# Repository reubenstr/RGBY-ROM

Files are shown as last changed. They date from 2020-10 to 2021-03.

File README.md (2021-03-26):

# RGBY-ROM

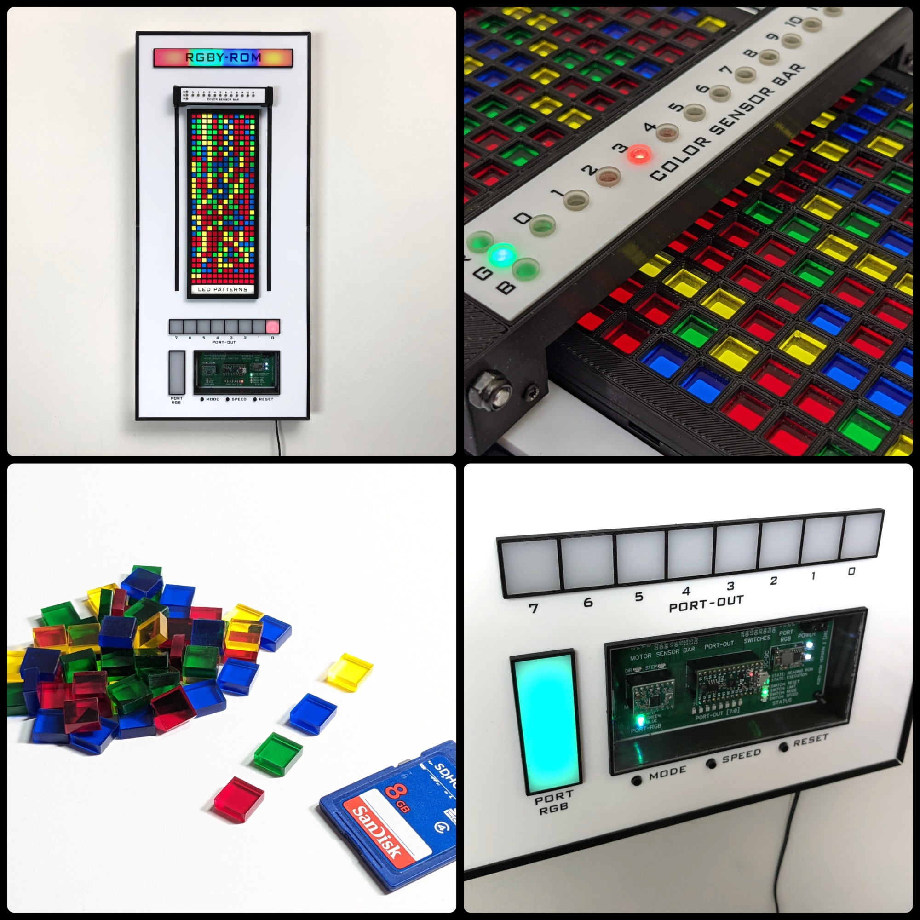
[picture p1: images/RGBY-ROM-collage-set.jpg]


RGBY-ROM reads data cartridges comprised of red, green, blue, and yellow acrylic squares where each square acts as 2 bits of program data. 

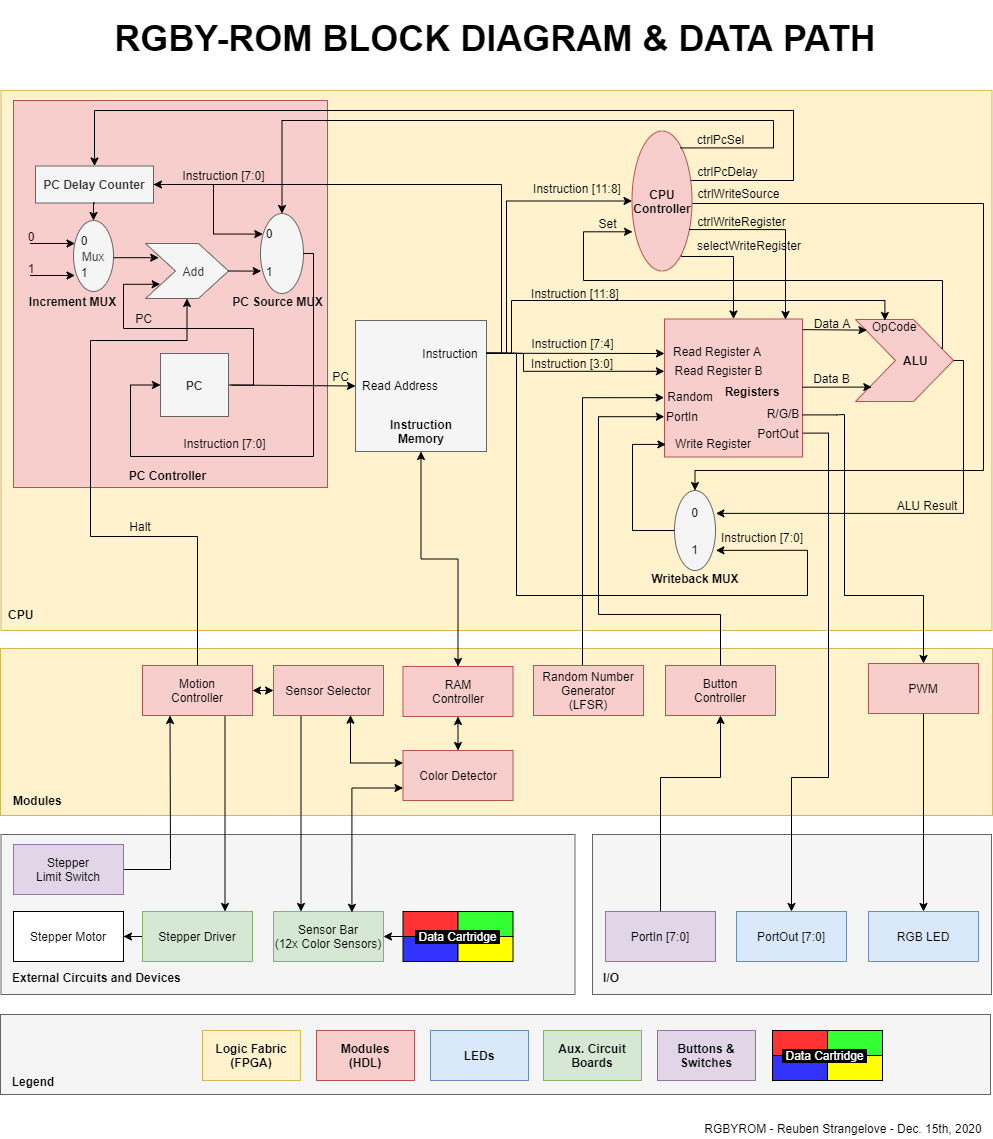
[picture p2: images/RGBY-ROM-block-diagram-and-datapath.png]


The the program is then excuted on a custom simple CPU architecture instantiated on a FPGA to control a RGB LED and 8 LED indicators.

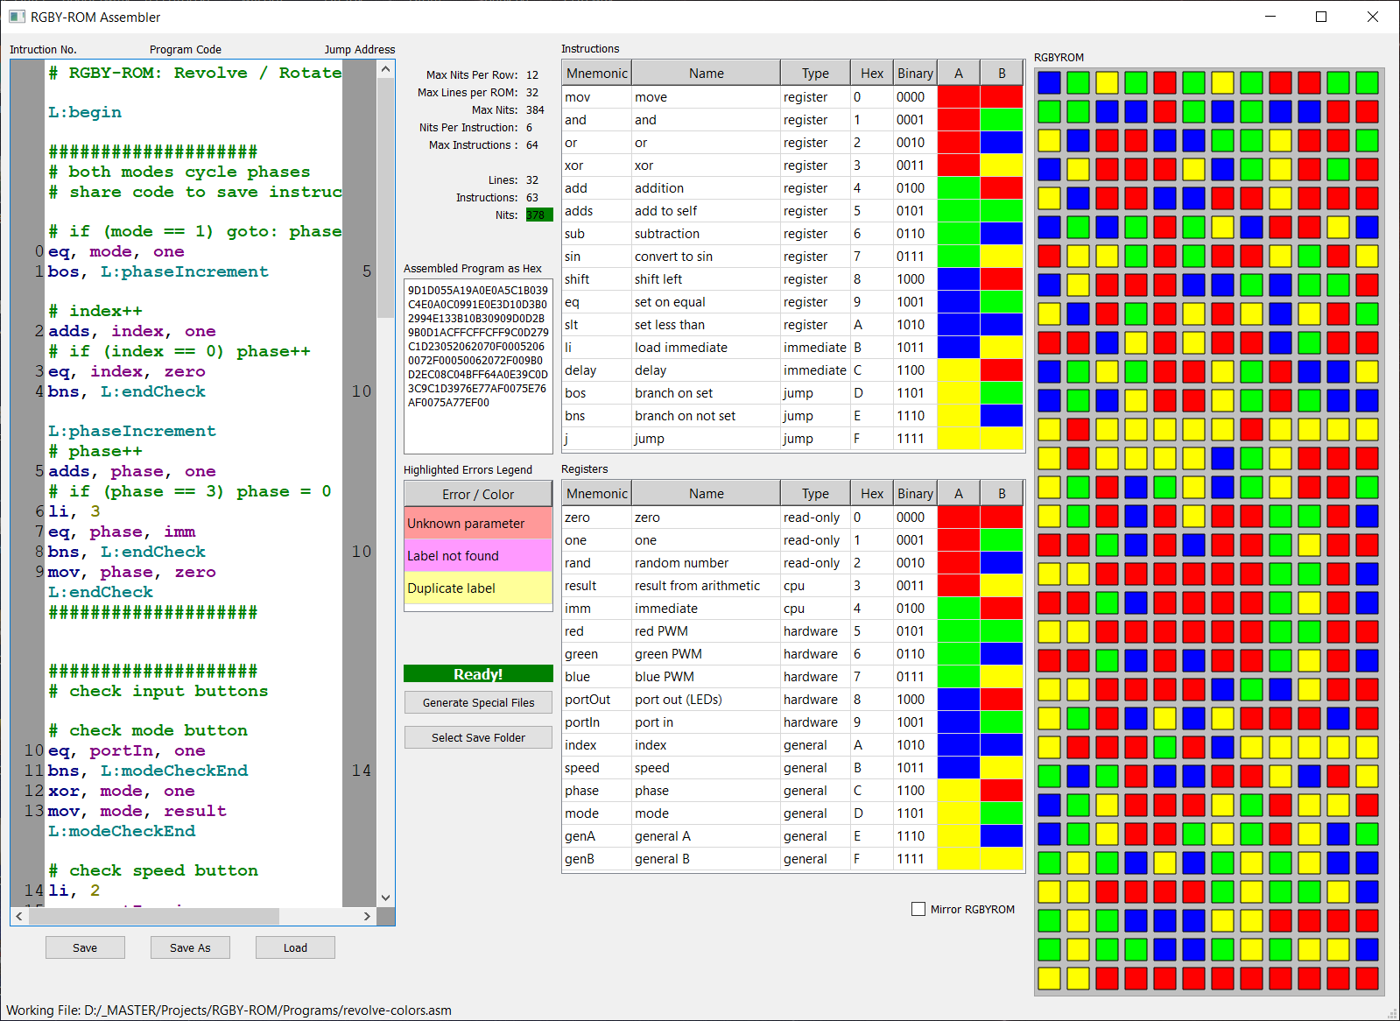
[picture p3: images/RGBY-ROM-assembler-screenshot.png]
 

The executed program is assembled using a custom assembler to create the data cartridge's color pattern.

RGBY-ROM uses the TinyFPGA Bx as the FPGA board the Verilog is developed useing the ATOM IDE with the APIO extension.

<br>

Blog post: https://metaphasiclabs.com/rgby-rom-custom-fpga-retro-cpu/

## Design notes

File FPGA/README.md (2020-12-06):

# RGBY-ROM

RGBY-ROM reads data cartridges using red, green, blue, and yellow acrylic squares as bit encoding.

***

RGBY-ROM uses the TinyFPGA Bx as the FPGA board.

The TinyFPGA uses the ATOM IDE with the APIO extension.

The HDL is Verilog.

The creator of TinyFPGA provide the following get started user guild: https://tinyfpga.com/bx/guide.html

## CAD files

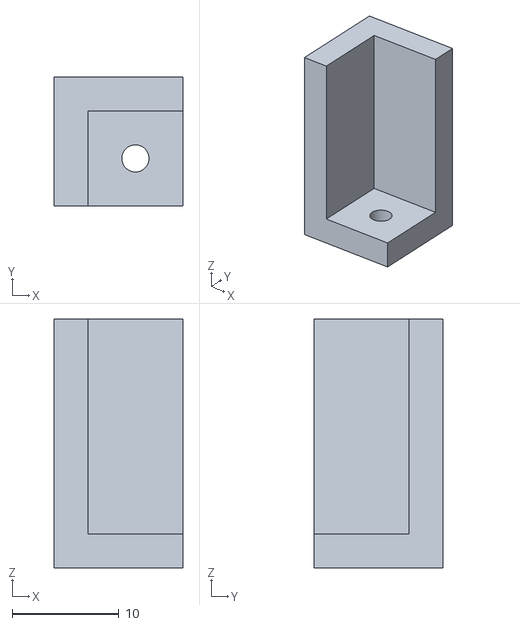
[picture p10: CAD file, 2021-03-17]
stl/RGBY-ROM-mainboard-backplate-corner-mount.stl
12.1 x 12.1 x 23.4

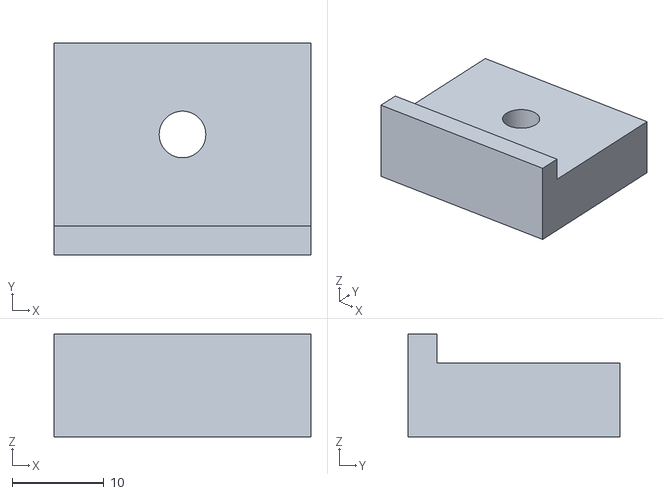
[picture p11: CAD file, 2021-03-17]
stl/RGBY-ROM-riser-a.stl
28.0 x 23.2 x 11.2

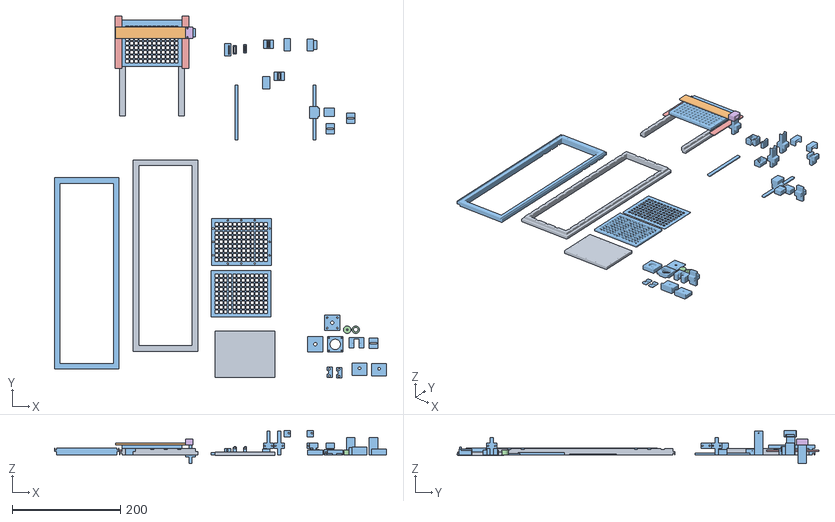
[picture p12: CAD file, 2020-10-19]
CAD/tinker.obj
613.5 x 667.9 x 61.1

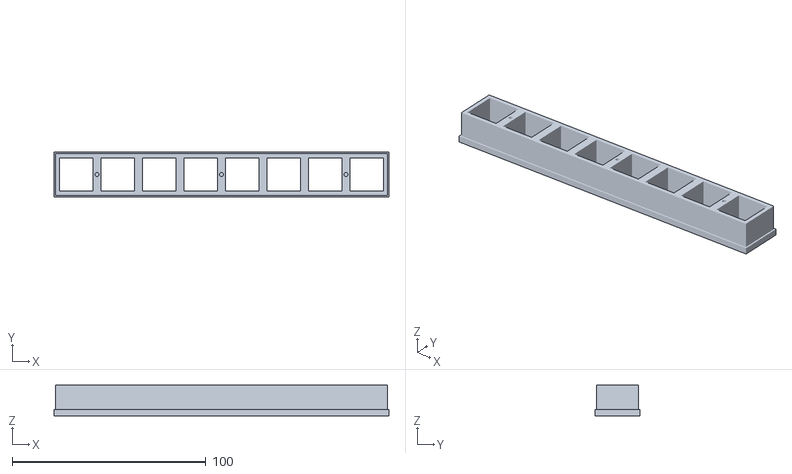
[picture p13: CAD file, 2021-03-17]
stl/RGBY-ROM-led-array-bezel.stl
172.7 x 23.0 x 15.9

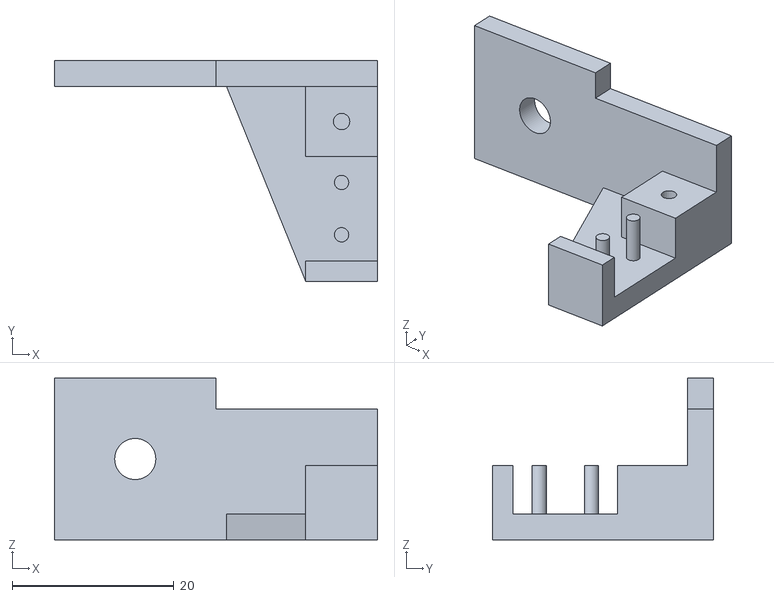
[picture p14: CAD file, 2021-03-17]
stl/RGBY-ROM-limit-switch-mounting-bracket.stl
40.0 x 27.3 x 20.0

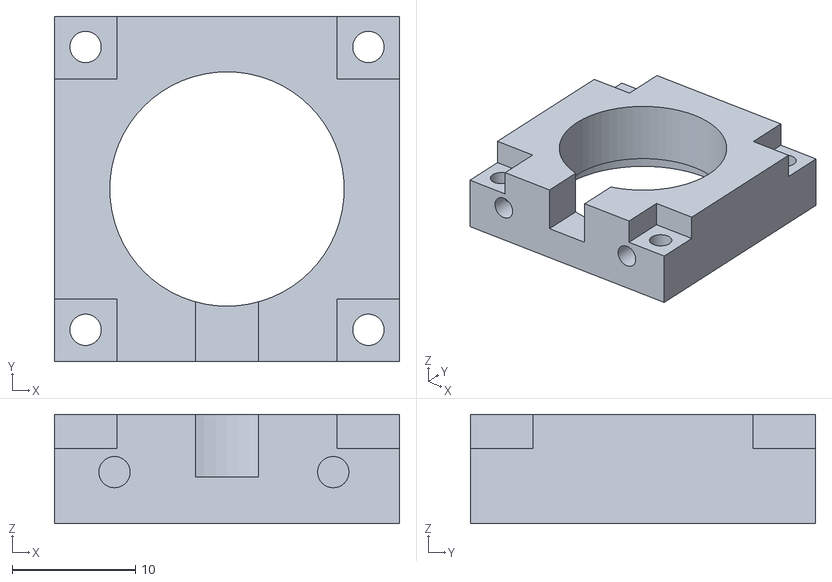
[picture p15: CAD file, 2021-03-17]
stl/RGBY-ROM-stepper-motor-mounting-bracket.stl
28.0 x 28.0 x 8.89

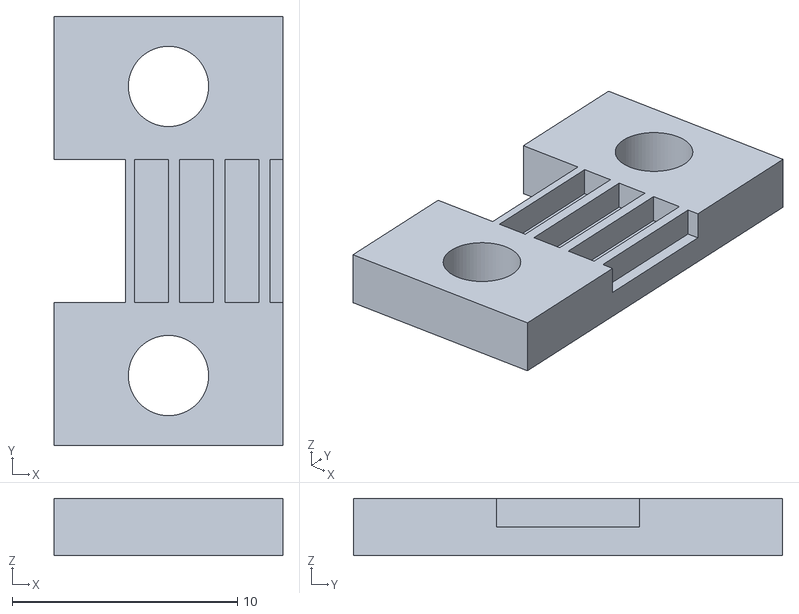
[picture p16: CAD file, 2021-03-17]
stl/RGBY-ROM-belt-hold-down.stl
10.2 x 19.1 x 2.54

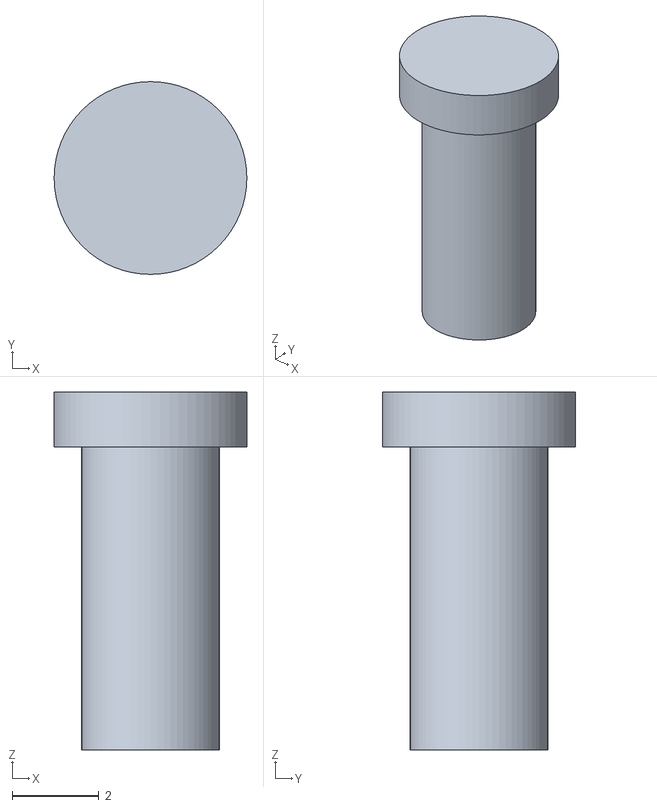
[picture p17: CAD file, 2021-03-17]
stl/RGBY-ROM-light-pipe-for-resin-printer.stl
4.44 x 4.44 x 8.26

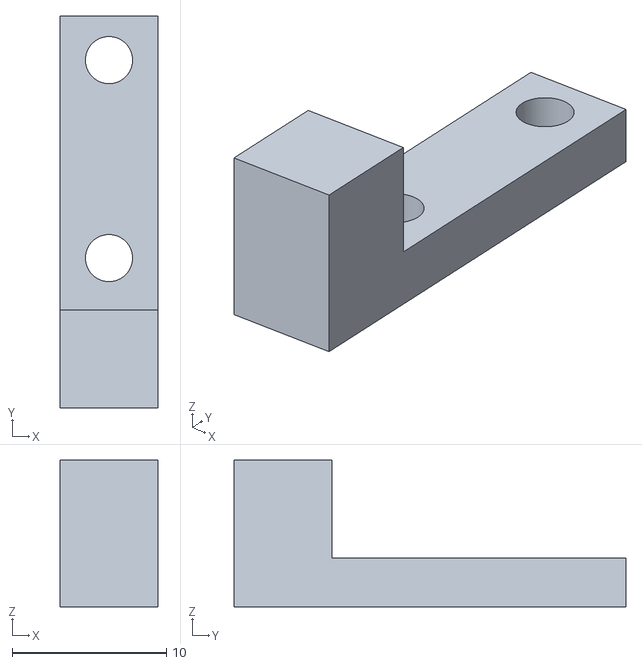
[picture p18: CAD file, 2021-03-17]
stl/RGBY-ROM-sensor-truck-limit-arm.stl
6.35 x 25.4 x 9.53

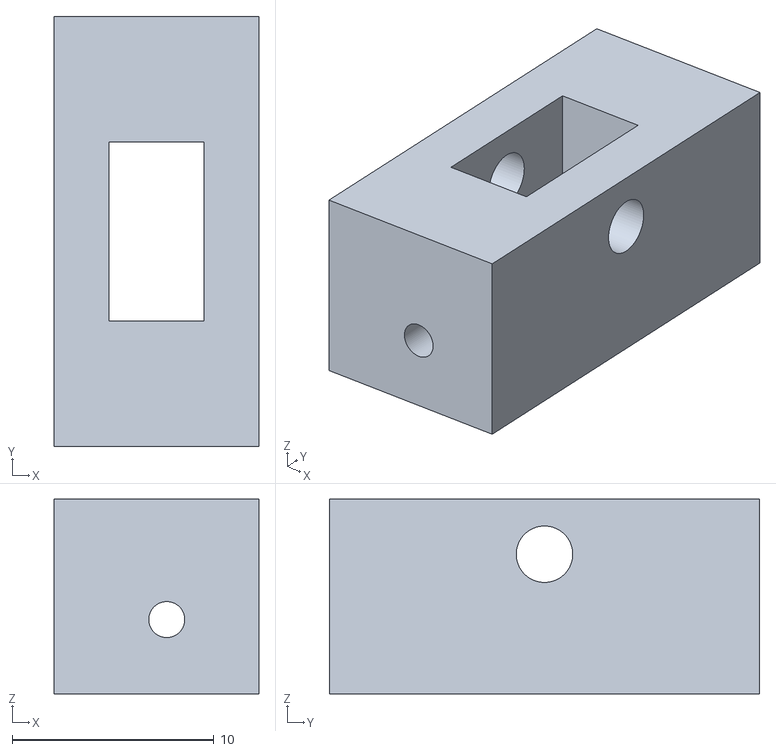
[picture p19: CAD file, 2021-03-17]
stl/RGBY-ROM-sensor-bar-bearing-block.stl
10.2 x 21.3 x 9.65

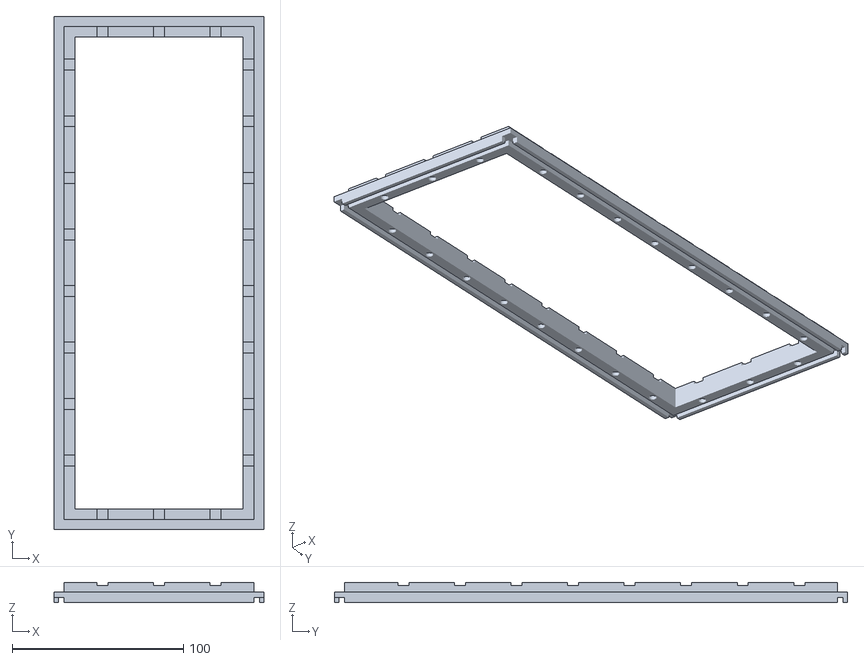
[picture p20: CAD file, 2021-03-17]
stl/RGBY-ROM-data-cartridge-magentic-mounting-bracket.stl
122.3 x 299.5 x 11.9

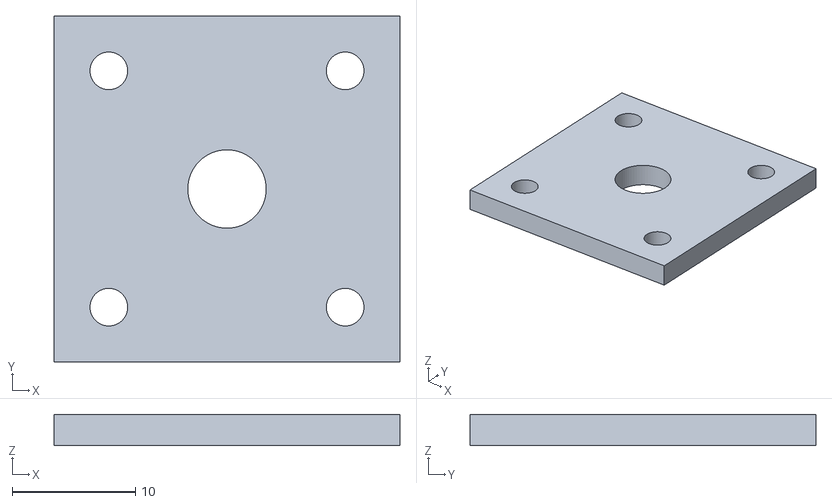
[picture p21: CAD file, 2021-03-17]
stl/RGBY-ROM-bearing-block-cover-plate.stl
28.0 x 28.0 x 2.54

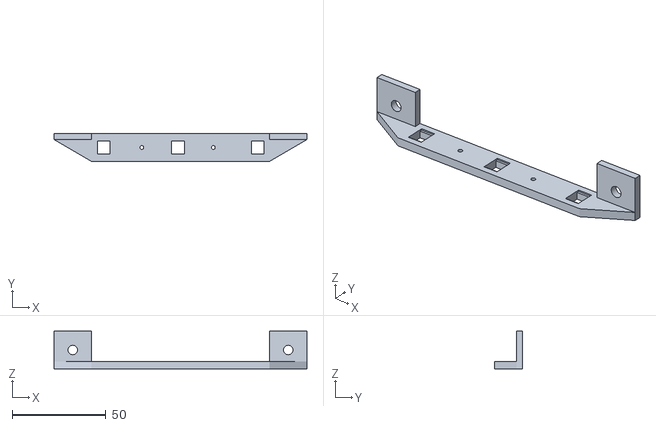
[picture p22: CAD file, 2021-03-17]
stl/RGBY-ROM-tact-switch-mounting-bracket.stl
134.8 x 14.8 x 20.0

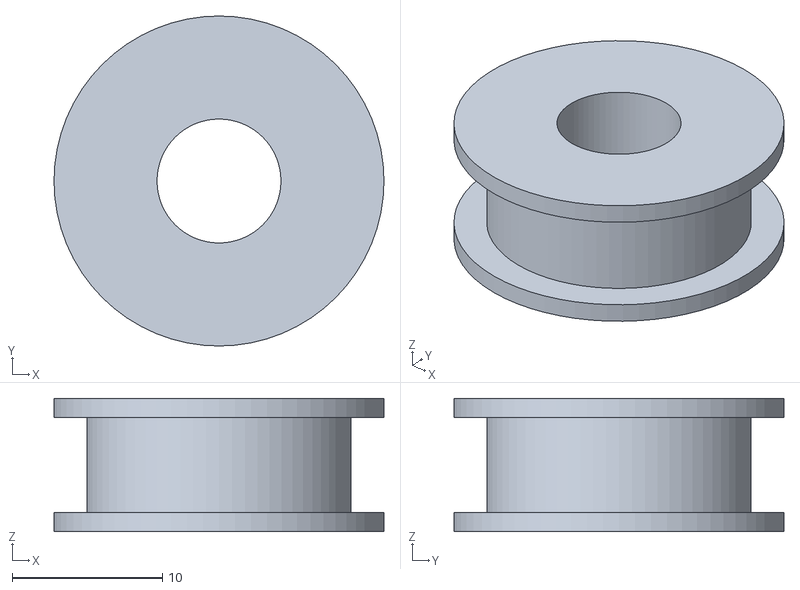
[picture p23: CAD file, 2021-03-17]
stl/RGBY-ROM-idler.stl
22.0 x 22.0 x 8.89

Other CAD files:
CAD/RGBYROM.dxf
stl/RGBY-ROM-nameplate-bezel.stl
stl/RGBY-ROM-data-cartridge-a.stl
stl/RGBY-ROM-bearing-block.stl
stl/RGBY-ROM-data-cartridge-b.stl
stl/RGBY-ROM-idler-mounting-bracket.stl
stl/RGBY-ROM-led-bezel-holddown-clip.stl
stl/RGBY-ROM-rgb-led-bezel-holding-clip.stl
stl/RGBY-ROM-rgb-led-bezel.stl
stl/RGBY-ROM-ribbon-cable-holding-bracket.stl
stl/RGBY-ROM-riser-b.stl
stl/RGBY-ROM-sensor-shield.stl
stl/RGBY-ROM-sensor-truck-channel-cap.stl
stl/RGBY-ROM-sensor-truck-no-wire-channel.stl
stl/RGBY-ROM-sensor-truck-wiring-channel.stl
stl/RGBY-ROM-tact-switch-holddown.stl
stl/RGBY-ROM-wire-mounting-bracket.stl

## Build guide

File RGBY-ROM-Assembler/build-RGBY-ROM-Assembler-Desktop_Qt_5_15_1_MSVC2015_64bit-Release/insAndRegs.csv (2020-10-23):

group | mnemonic | name | type
instruction | mov | move | register
instruction | and | and | register
instruction | or | or | register
instruction | xor | xor | register
instruction | add | addition | register
instruction | adds | add to self | register
instruction | sub | subtraction | register
instruction | sin | convert to sin | register
instruction | shift | shift left | register
instruction | eq | set on equal | register
instruction | slt | set less than | register
instruction | li | load immediate | immediate
instruction | delay | delay | immediate
instruction | bos | branch on set | jump
instruction | bns | branch on not set | jump
instruction | j | jump | jump
register | zero | zero | read-only
register | one | one | read-only
register | rand | random number | read-only
register | result | result from arithmetic | cpu
register | imm | immediate | cpu
register | red | red PWM | hardware
register | green | green PWM | hardware
register | blue | blue PWM | hardware
register | portOut | port out (LEDs) | hardware
register | portIn | port in | hardware
register | index | index | general
register | speed | speed | general
register | phase | phase | general
register | mode | mode | general
register | genA | general A | general
register | genB | general B | general

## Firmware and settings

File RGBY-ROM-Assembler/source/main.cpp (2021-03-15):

/*
	RGBY-ROM Assembler
	Reuben Strangelove
	03/19/2019
	
	Visual assembler for RGBY-ROM assembly code programs.
	
	Project details: https://github.com/reubenstr/RGBY-ROM
*/

#include "mainwindow.h"
#include <QApplication>

int main(int argc, char *argv[])
{
    QApplication a(argc, argv);
    MainWindow w;
    w.show();

    return a.exec();
}

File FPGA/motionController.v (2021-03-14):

// Controller for the stepper motor during data cartridge read operation.
module motionController (
  input clk,
  input reset,
  input limitSwitch,
  input selectorComplete,
  output reg startSelector,
  output reg direction,
  output step,
  output motionControllerCompleted);

  // http://buildlog.net/cnc_laser/belt_calcs.htm
  // 200 steps per revolution
  // 8 microsteps
  // 36 teeth per head
  // 0.080" belt pitch
  // 555.556 steps per inch
  // 0.325" nit center to center, 180.5557 steps nit center to center.
  parameter [10:0] STEPS_BETWEEN_ROWS = 183;
  parameter [10:0] FIRST_ROW_STEPS_AFTER_HOME = 610;

  // Set the speed of the stepper.
  parameter [15:0] CYCLES_BETWEEN_STEPS = 512;

  reg [3:0] state;
  parameter [3:0] HOME = 0, MOVE_TO_FIRST_ROW = 1, TRAVERSE = 2, SCAN = 3, PARK = 4, FINISHED = 5;
  initial state = HOME;
  parameter UP = 1, DOWN = 0;

  assign motionControllerCompleted = (state == FINISHED);

  reg moveFlag;
  reg stepSignal;
  reg [15:0] stepCount;
  reg [4:0] rowCount;

  pulseExtender pulseExtender1(.clk(clk), .reset(reset), .signal(stepSignal), .extendedSignal(step));

  // State machine.
  always@(posedge clk or posedge reset)
    if(reset) begin
      state <= HOME;
      rowCount <= 0;
    end else begin

    case(state)

      HOME : begin
        if (limitSwitch == 1) begin
          direction <= DOWN;
          moveFlag <= 0;
          state <= MOVE_TO_FIRST_ROW;
        end else begin
          direction <= UP;
          moveFlag <= 1;
        end
      end

      MOVE_TO_FIRST_ROW : begin
        if (stepCount == FIRST_ROW_STEPS_AFTER_HOME)
          begin
            moveFlag <= 0;
            startSelector <= 1;
            state <= SCAN;
          end else begin
              moveFlag <= 1;
          end
      end

      TRAVERSE : begin
        if (stepCount == STEPS_BETWEEN_ROWS)
          begin
            moveFlag <= 0;
            startSelector <= 1;
            state <= SCAN;
          end else begin
            moveFlag <= 1;
          end
      end

      SCAN : begin
        startSelector <= 0;
        if (selectorComplete == 1)
        begin
          rowCount <= rowCount + 1;
          if (rowCount == 31)
          begin
            state <= PARK;
          end else begin
              state <= TRAVERSE;
          end
        end
      end

      PARK : begin
        if (limitSwitch == 1) begin
          direction <= DOWN;
          state <= FINISHED;
        end else begin
          direction <= UP;
          moveFlag <= 1;
        end
      end

      FINISHED : begin
        moveFlag <= 0;
      end

    endcase
  end

  // Step every X clock signals on set flag.
  // Count steps.
  reg [23:0] delayCounter;
  always@(posedge clk or  posedge reset)
    if(reset) begin
       stepSignal <= 0;
       stepCount <= 0;
       delayCounter <= 0;
    end
  else begin
    if (moveFlag) begin
      if (delayCounter == CYCLES_BETWEEN_STEPS) begin
        delayCounter <= 0;
        stepSignal <= 1;
        stepCount <= stepCount + 1;
      end else begin
        delayCounter <= delayCounter + 1;
        stepSignal <= 0;
      end
    end else begin
      stepSignal <= 0;
      delayCounter <= 0;
      stepCount <= 0;
    end
  end

endmodule

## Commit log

2020-10-20 Tweaks all systems.
    [insAndRegs.csv]
2020-10-21 Bug smashes, asm program working.
    [insAndRegs.csv]
2020-10-23 Sensor board testing and tweaks.
    [insAndRegs.csv]
2020-10-24 Updated PCB
2020-10-26 PCB update.
2020-11-12 Swap from test bed to PCB.
2020-11-24 Added mirroring to assembler.
2021-03-17 STL upload.
    [RGBY-ROM-bearing-block-cover-plate.stl, RGBY-ROM-bearing-block.stl, RGBY-ROM-belt-hold-down.stl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]
